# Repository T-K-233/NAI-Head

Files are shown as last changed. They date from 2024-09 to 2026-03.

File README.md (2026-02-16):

# An animatronic head

Note: The original code and report is stored on [ee249 branch](https://github.com/T-K-233/NAI-Head/tree/ee249).

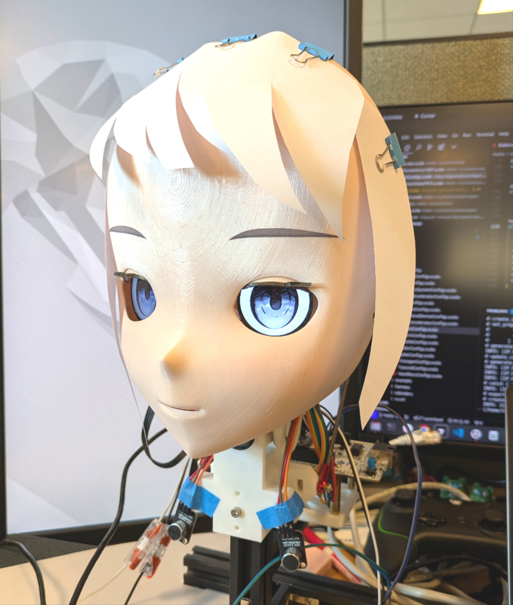
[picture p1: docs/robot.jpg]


This project presents the development of an anime-inspired robotic head designed for cyber-physical systems research, integrating advanced computational techniques, aesthetic considerations, and mechanical engineering. The system features a multi-platform architecture that combines STM32 microcontrollers, FPGA-based gesture recognition, and neural networks deployed on edge AI devices. By coordinating eye and head movements and dynamically responding to user interactions, the robot achieves lifelike and engaging interactions. The implementation of gesture recognition through machine learning, along with finite state machine-based behavior control, enhances the robot's capability for natural human-robot interactions. The mechanical structure, created using OnShape and Blender, supports versatile movement and expressive gestures. 

## Directory Structure

`Baremetal-IDE/` and `Baremetal-NN/` contain the code for setting up a baremetal environment from scratch on RISC-V platforms and runs the neural network inference. It also includes a Python script for C code generation from a PyTorch model.

`firmware/` contains the firmware for the STM32 microcontroller. We use STM32F446 for functional prototyping of each module, and integrate the final project on STM32F429. The `convert.py` script is used to generate the binary RGB565 image from the original PNG file for the LCD display.

`host/` contains bridge code for interacting with the VTubeStudio software.

`MaDa/` contains the code for generating the FPGA bitstream to perform edge inference on RISC-V design on FPGA.

`mechanical/` contains the intermediate files for building the mechanical structure of the robot. The rest of the files are available in the [Onshape project](https://cad.onshape.com/documents/7b6f8264bfc266305901c995/w/1ddfe8bb1118d3d58069c09d/e/082a5b68c1e32d8598ae1104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).

`neural/` contains the gesture recognition model and the code for training and inference on host PC.

## Hardware Setup

### Wiring

| Index | Board Pin | STM32 Pin (L) | STM32 Pin (R) | Description |
| ----- | --- | --- | --- | --- |
| 1 | GND | GND | GND | Ground |
| 2 | VIN | 3V3 | 3V3 | Power, 3.3V ~ 5V |
| 3 | SCL | PA5 (SCLK) | PB13 (SCLK) | SPI clock input |
| 4 | SDA | PA7 (MOSI) | PB15 (MOSI) | SPI data input |
| 5 | RES | PA9 | PB2 | Reset, active low |
| 6 | DC | PA8 | PB1 | Data / Command select, low: command; high: data  |
| 7 | CS | PB6 | PA11 | SPI chip select, active low |
| 8 | BLK | PC7 | PB12 | Backlight enable, default pull-up to 3V3 |

### Peripheral Allocation

#### SPI

- Frame Format: Motorola
- Data Size: 8 bits
- First Bit: MSB First
- Baud Rate: 20 Mbps
- Clock Polarity: Low
- Clock Phase: 1st Edge
- NSS Signal: Software Controlled

#### Timer

- Prescaler: 79
- Counter Mode: Up
- Counter Period: 19999
- PWM Generation
  - PWM Mode: Mode 1
  - Pulse: 1500
  - Output Compare Preload: Enable
  - Fast Mode: Disable
  - CH Polarity: High
 
### Clock Tree Settings

SPI1 and TIM1, TIM8 are under the high speed APB2 bus; SPI2 and TIM2-7 are under APB1 bus. This information can be verified in Table 1 of [RM0090
Reference manual](https://www.st.com/resource/en/reference_manual/dm00031020-stm32f405-415-stm32f407-417-stm32f427-437-and-stm32f429-439-advanced-arm-based-32-bit-mcus-stmicroelectron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).

APB1 bus is configured to have 40 MHz clock (PCLK1 = 40 MHz, 45 MHz max); APB2 bus is configured to have 80 MHz clock (PCLK2 = 80MHz, 90 MHz max).

We need to configure the prescaler of each peripheral accordingly.

### Communication Frame

#### UDP Frame

| Idx | Name | Byte Range | Type |
| --- | --- | --- | --- |
| 0 | Head X | 0:4 | float32 |
| 1 | Head Y | 4:8 | float32 |
| 2 | Head Z | 8:12 | float32 |
| 3 | Eye Left X | 12:16 | float32 |
| 4 | Eye Left Y | 16:20 | float32 |
| 5 | Eye Right X | 20:24 | float32 |
| 6 | Eye Right Y | 24:28 | float32 |
| 7 | Eye Left Openness | 28:32 | float32 |
| 8 | Eye Right Openness  | 32:36 | float32 |

## Solving Protobuf issue in Windows

```powershell
$env:PROTOCOL_BUFFERS_PYTHON_IMPLEMENTATION = "python"
```

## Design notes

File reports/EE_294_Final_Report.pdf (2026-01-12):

# An Anime Figure Robot Head for Cyber-Physical Systems Research

Yufeng Chi∗
chiyufeng@berkeley.edu

Jingyi Xu∗
jingyixu@berkeley.edu

Abstract—This project presents the development of an anime-inspired robotic head designed for cyber-physical systems research, integrating advanced computational techniques, aesthetic considerations, and mechanical engineering. The system features a multi-platform architecture that combines STM32 microcontrollers, FPGA-based gesture recognition, and neural networks deployed on edge AI devices. By coordinating eye and head movements and dynamically responding to user interactions, the robot achieves lifelike and engaging interactions. The implementation of gesture recognition through machine learning, along with finite state machine-based behavior control, enhances the robot’s capability for natural human-robot interactions. The mechanical structure, created using OnShape and Blender, supports versatile movement and expressive gestures. This work not only addresses challenges like the uncanny valley effect but also establishes a foundation for future advancements in humanoid robotic systems, with potential applications in entertainment, education, and human-computer interaction.

I. INTRODUCTION
The design and functionality of humanoid robots have advanced significantly in recent years, yet achieving natural and engaging human-robot interactions remains a considerable challenge. A key obstacle is the ”uncanny valley” effect [6, 7], where robots that closely resemble humans but display subtle imperfections in appearance or behavior evoke discomfort or unease in observers. Addressing this phenomenon requires a combination of stylized aesthetic design [5] and smooth, responsive motion control to enhance user perception and interaction quality.
Al-Sada et al. approaches this challenge by implementing a humanoid robot that incorporates anime-inspired behaviors and interactions, utilizing teleoperation and imitation-learned control policies. However, their work does not fully explore the computational requirements or input modalities needed for a seamless user experience.
Building on these concepts, this work introduces an anime-styled robotic head equipped with multiple computing components, shown in Figure 1, designed to express emotions through coordinated eye and head movements while dynamically responding to user interactions. This platform serves as a foundation for exploring advanced motion control strategies and optimizing workload scheduling for multitenant systems, ultimately contributing to more fluid and lifelike human-robot interactions. The codebase can be accessed from https: //github.com/T-K-233/NAI-Head.

*These authors contributed equally to this work


Fig. 1: The anime-styled robotic head with ability to express motions via eye and head movements.

II. THE ROBOT PLATFORM

The system is composed of three compute platforms. The host computer reads in camera frames from the camera and performs the front-end detection of the user gesture. The detected hand keypoints will then be sent to the RISC-V processor running on Arty FPGA for classification and detects a motion label from the landscape. Lastly, the user gesture is transmitted to the STM32 microcontroller, which controls both the microphones, the TFT LCD screens, and the various servo actuators. The system are connected together with Ethernet interface under a same local subnet, and the data packets are transmitted with UDP frames. In Section III we introduce the workload and static scheduling on the STM32 microcontroller; in Section IV we introduce the neural network running on baremetal environment; and in Section VII we introduce the software running on the host PC.
The mechanical structure of the robot is designed with OnShape and Blender, and manufactured with 3D printing fabrication method. More detail on this is covered in Section VIII

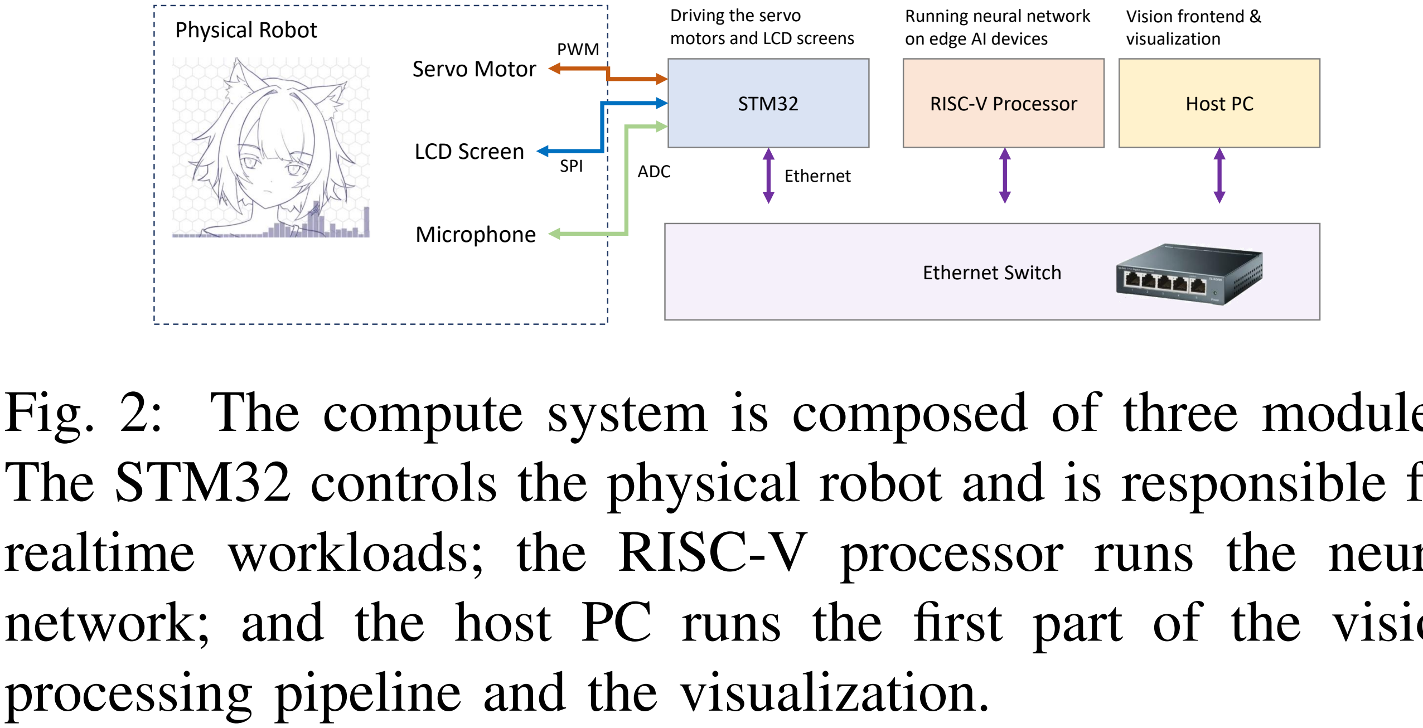
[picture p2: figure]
Ethernet Switch; STM32; Physical Robot; RISC-V Processor; Host PC; Servo Motor; LCD Screen; PWM; ADC; Ethernet; Running neural network on edge AI devices; Driving the servo motors and LCD screens; Vision frontend & visualization; Microphone; SPI; processing pipeline and the visualization.

Fig. | 2: The compute system is composed of three modules.
The | STM32 controls the physical robot and is responsible | for
realtime workloads; the RISC-V processor runs the neural network; and the host PC runs the first part of the vision

III. THE STM32 MICROCONTROLLER

The STM32 microcontroller is responsible for real-time sensing and control of the robot’s input/output (I/O) operations.
Given the platform’s resource constraints and the strict deadlines associated with multiple real-time tasks, a feasible static schedule is crucial to ensure timely and successful program execution.
A. Processor Selection

The STM32 product family offers a wide range of options for embedded processing. The STM32F429ZI microcontroller unit (MCU) was selected based on the following criteria:
- Availability of the Nucleo development board for the selected MCU.
- Availability of required I/O ports, particularly the Ethernet port.
- Availability of resources, such as tutorials and example projects.
- Cost-effectiveness of the development board.
- Compact size and lightweight design.
B. Workload Description

The STM32 controller executes several tasks, prioritized based on their real-time requirements.
1) Audio Sampling
The audio sampling task continuously reads microphone input using the analog-to-digital converter (ADC) at a 25 kHz sampling rate for short durations. While the ADC acquires new samples, previously captured data is transferred to SRAM via direct memory access (DMA) engines.
The microphones are mounted on the same plane, roughly 100 mm apart. Two example signals from the microphone array are shown in Figure 3. A cross-correlation algorithm is then applied to the sampled data from the left and right microphones to determine the time delay corresponding to the peak correlation value. This time delay indicates the angle of the sound source.
2) LCD Control
The LCD driver is another time-sensitive workload. Two TFT LCDs, each driven by the GC9A01A IC, are connected to the STM32 via SPI buses. During each frame update, the driver transmits the coordinates of the first pixel along with

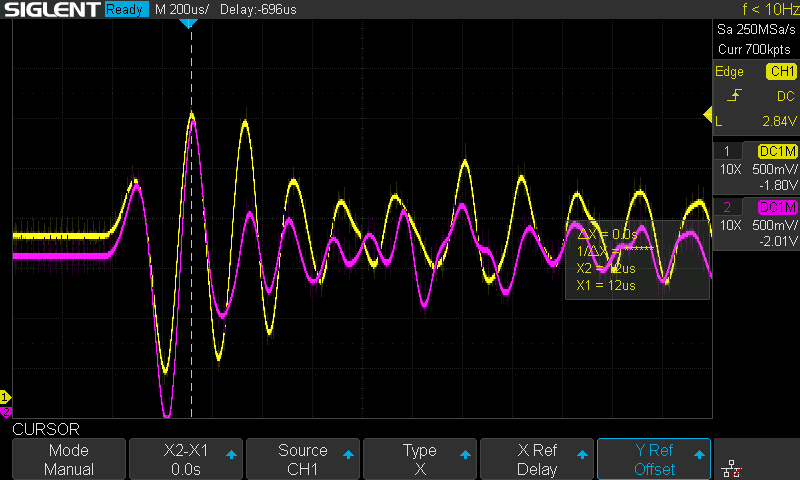
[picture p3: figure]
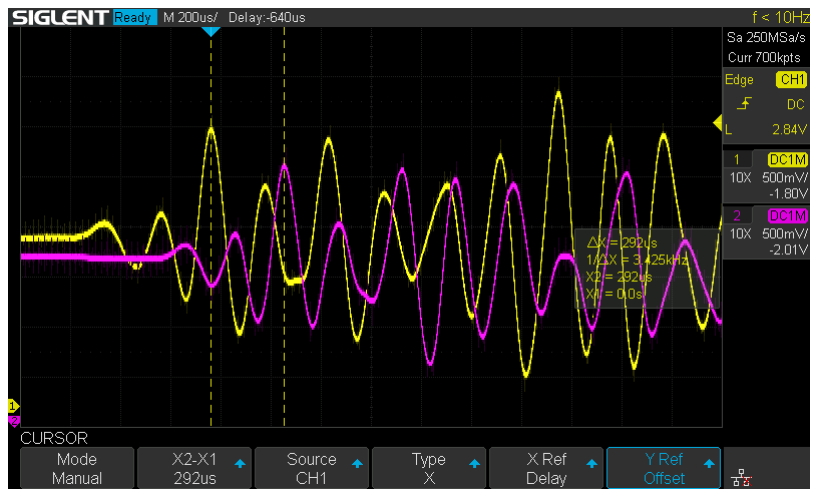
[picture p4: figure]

(a) Sound coming from middle | (b) Sound coming from left
Fig. 3: The analog signals from the microphone. The signals are centered around 1.65V, and the amplitude corresponds to the amplitude of the sound. The phase shift between the two signals roughly translates to the angle of the sound source from the plane of the two microphones.

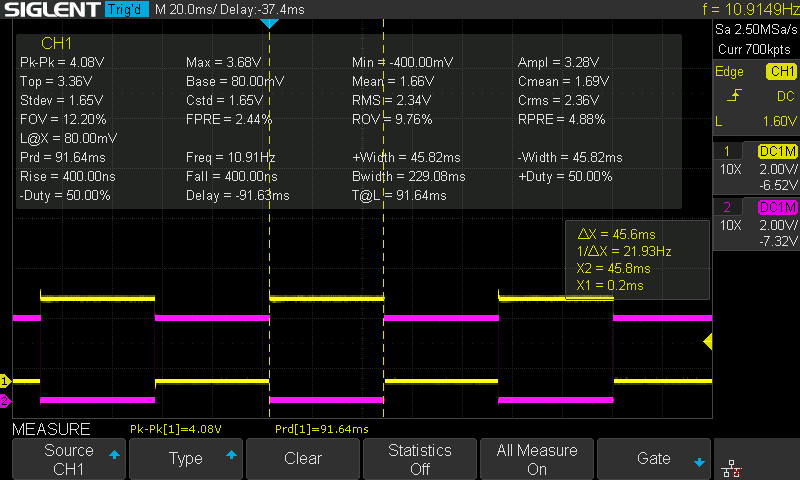
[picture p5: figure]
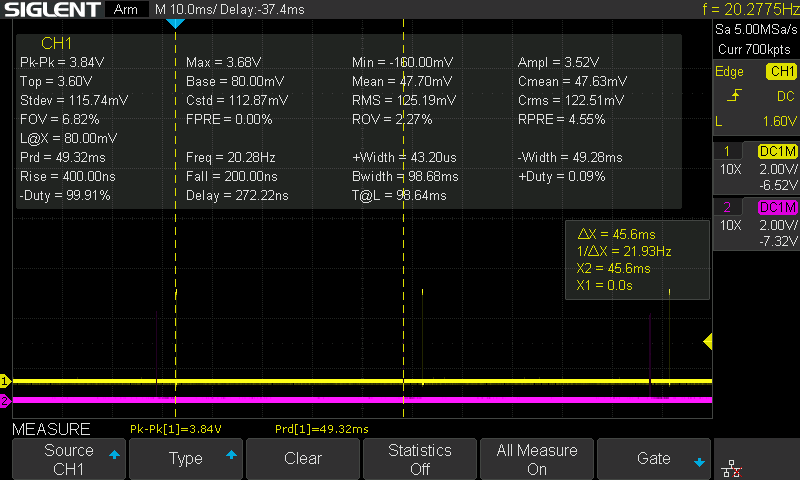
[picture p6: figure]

(a) SPI transmit in polling mode (b) SPI transmit in DMA mode
Fig. 4: The CPU utilization when transmitting SPI data in polling mode and in DMA mode. (a) The yellow line shows the CPU’s state when transmitting on SPI4, where a high level indicates that the CPU actively transmitting, and a low level indicates the CPU is available for other tasks, and the magenta line indiates the CPU state on SPI5. It can be observed that the two SPI transaction takes up entire CPU cycles, which prevents other tasks from being executed. (b) The yellow line shows the begin of a SPI transaction with DMA, and the magenta line shows the corresponding interrupt that configures the CS pin, indicating the end of a transaction.

the image dimensions to the GC9A01A control registers. It then streams pixel data to the display buffer.
Each pixel is encoded in a 565 format, combining 5-bit red, 6-bit green, and 5-bit blue values into two bytes. Given the 240x240 resolution of the LCD, each frame requires transferring 115,200 bytes of data. To reduce CPU load, DMA is employed to handle data transfer, allowing the CPU to perform other tasks concurrently. Figure 4 shows a comparision between using blocking polling transfer and DMA transfer.
3) Servo Control
To control the robot’s five servos, five PWM signals are generated with a 50 Hz period and pulse durations ranging from 500 µs to 2500 µs. The hardware timers on the STM32 are used to generate these PWM signals, minimizing CPU involvement. The CPU only updates the Capture/Compare Register (CCR) values to adjust pulse durations.
4) UDP Communication
The final task involves handling UDP communication between the STM32 and other components of the robot system. The implementation leverages the STM32CubeIDE libraries, which support multiple layers of the OSI model. Specifically:

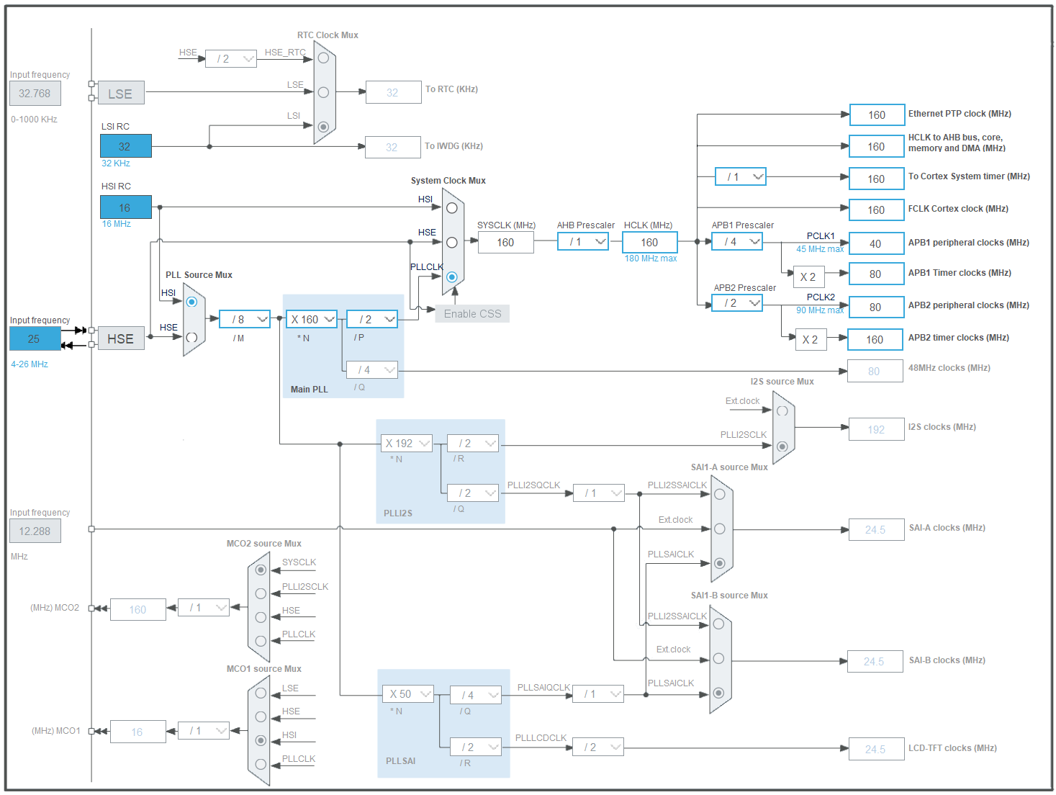
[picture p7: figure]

Fig. 5: The clock tree of the STM32F429ZI. System clock is set to 160 MHz, generated from the main PLL. APB1 and APB2 peripherals are set to their maximum possible clock frequencies, which is 40 MHz and 80 MHz respectively.

- Physical and Data Link Layers: Managed using the
onboard Ethernet (ETH) peripheral.
- Network Layer: Handled by the Lightweight IP (LWIP) stack.
- Transport Layer: Implemented using the example code from Controllerstech.
This modular approach ensures efficient and reliable UDP communication while meeting the real-time constraints of the system.
C. MCU Resource Allocation

Since none of the tasks requires high precision clocks, the clock source of the MCU is configured to be the hightspeed internal RC oscillator (HSI). The system clock is then generated from the on-chip PLL. We select 160 Mhz to be the system clock as it is sufficiently fast, easily dividable into other slower clock domains, and provides enough headroom to the absolute maximum 180 MHz. The resulting clock tree is shown in Figure 5.
Timer 6 and Timer 7 are used to generate interrupt events for SPI and PWM updates. Timer 6 is configured to trigger an interrupt at 10 Hz interval, while Timer 7 is configured to trigger at 50 Hz.
Timer 1 and Timer 4 are used to generate the PWM signal for the five servo motors. They are configured at the start of the application program, and the values are updated in the interrupt handler of Timer 7.

Timer 2 is used as the trigger source for ADC sampling. When update event happens, it generates a signal on the trigger output (TRGO) pin, which will send to the ADC and starts the sampling and conversion. The ADC will then communicate with the DMA engine to perform a predefined number of conversions, and writes the data to a target SRAM location via DMA.
SPI4 and SPI5 are used to drive the TFT LCD screens. For the control commands, they are operating in the blocking polling and in 8-bit mode. After transmitting the command, it is updated to operate in non-blocking DMA mode and in 16-bit transfer mode. Since the chip select (CS) pins are controlled by software, an interrupt handler is set up to write the CS pins high after the data transfer.
Ethernet and the corresponding software library for UDP logic is running entirely in the main thread.
The IOs are planned with the wire harnessing in mind. The resulting pinmap is shown in Figure 6.

IV. THE VISION PIPELINE

The gesture recognition pipelines goes through three stages. First, when users pose, the camera video input is captured and pre-processed. Next, we use mediapipe library to extract the hand keypoints from the image. Lastly, the hand keypoint features are fed into a MLP network to classify the input hand gesture into one of hi, ok, no, point, heart. The output is sent over to STM32 to drive robot behaviors.

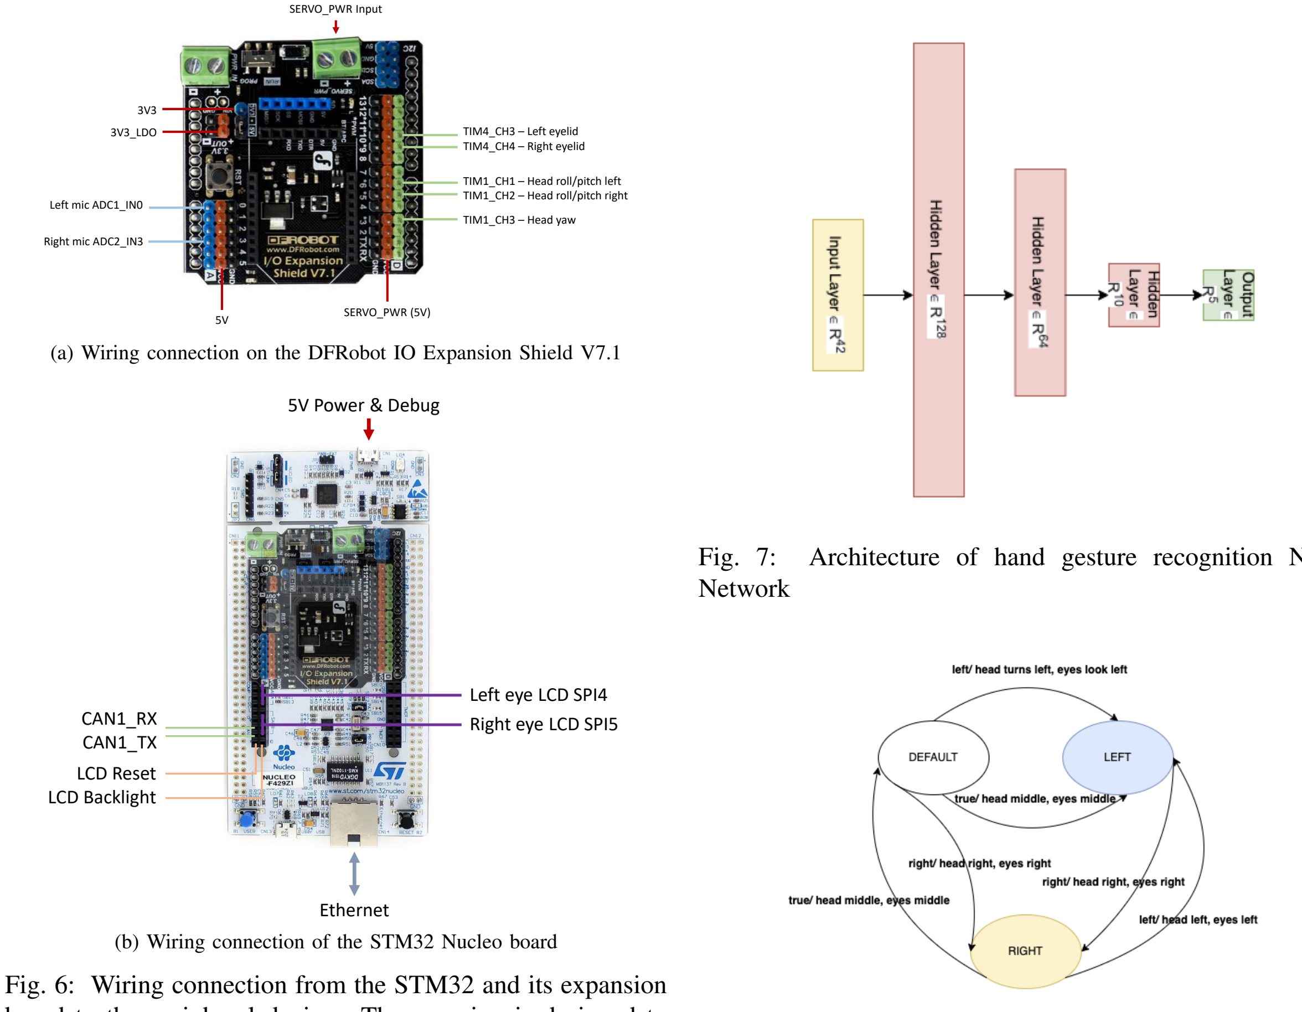
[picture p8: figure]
TIM4_CH3 – Left eyelid TIM4_CH4 – Right eyelid; TIM1_CH1 – Head roll/pitch left TIM1_CH2 – Head roll/pitch right; TIM1_CH3 – Head yaw; SERVO_PWR (5V) 5V; 3V3_LDO; Left mic ADC1_IN0; SERVO_PWR Input; Right mic ADC2_IN3; CAN1_RX CAN1_TX; Ethernet; LCD Reset LCD Backlight; Left eye LCD SPI4 Right eye LCD SPI5; 5V Power & Debug; Network

(a) Wiring connection on the DFRobot IO Expansion Shield V7.1
(b) Wiring connection of the STM32 Nucleo board
Fig. 6: Wiring connection from the STM32 and its expansion board to the peripheral devices. The mapping is designed to group pins with similar functions together.

The model’s architecture is shown in Figure 7. It takes the 21 hand landmarks as input and runs through 3 hidden layers and outputs probabilities for each of the 5 labels, the highest of which selected as prediction label. This model is designed to be lightweight to be deployed on edge computing platforms including K230 and soft RISC-V core on FPGA. To train this model, we collected our custom dataset of 5000 samples. We trained the model from scratch and it achieves 97.2% accuracy.

To port the neural network to embedded runtime, we first implemented the C runtime and syscall handlers (libgloss layer) in Baremetal-IDE. In addition, we built the Baremetal-NN library to convert the pytorch model to embedded RISC-V environment. We successfully ported our custom pytorch model to K230 chip. We also generated a corresponding RISC-V RV32IMAFC TinyRocket SoC design on FPGA, leveraging the Ethernet controller IPs provided by Xilinx to perform UDP communication.

Fig. 7: Architecture of hand gesture recognition Neural

Fig. 8: FSM capturing the robot’s reaction with respect to sound input(from left or right).

V. ROBOT FINITE STATE MACHINE

We define the Robot’s behavior using two finite state machines. The first reacts to input sounds. Figure 8 shows that the robot turns its head and eyes to the direction of sound input.
The robot’s reaction to user’s hand gesture is represented as a one-state Mealy Machines, where the output solely depends on the input. The input/output relation is summarized in the lookup table in Table I.
gesture | eyes | head
Hi | enlarged | tilt
Ok | open | nod
No | closed | shake
Point | wink | tilt
Heart | heart eyes | stay still

TABLE I: The robot’s behavior w.r.t hand gesture inputs.

VI. EMBEDDED RUNTIME

Since we are in a baremetal RISC-V environment, we need to construct the C runtime from the ground up. We build the glossy library, our own implementation of the libgloss layer, to provide the basic startup and C runtime assembly program, as well as the basic implementation of system call routines. On bootup, the program counter (PC) of the Rocket core is pointed at BootROM, located at 0x00010000. Then, the BootROM code will guide the PC to perform basic initializations, and jumps to the base of the on-chip SRAM region located at 0x80000000. There, it enters our start up script ”crt0.S”, which initializes the system state by setting general-purpose registers, floating-point unit (if available), global pointer, thread-local storage, stack pointer, and memory segments (data, BSS). It then invokes global constructors, calls the main function for the primary core, and loops indefinitely after program termination, while secondary cores follow a similar initialization path to run main.
A custom linker script is also created to instruct linker to put sections to corresponding locations. The mapping is shown in Figure 9.

__text_start

.text

.rodata

.data

.tdata

.sdata

.bss

.tbss

.heap

.stack

0x8000_0000

__text_end

__data_start | __data_load_start

__text_load_start

__global_pointer$

__tdata_start

__data_end, __tdata_end __tbss_start

__tbss_end __bss_start

__bss_end

__end, __head_start

__head_end

__stack_start

__sp, __stack_end

Fig. 9: Memory map specified by the linker script. The map starts at SRAM base address at 0x80000000, and follows the convention of text, data, heap, and stack layout. The left side shows the symbols pointing to logical address, and the right side shows the symbols with physical address. The gray bar shows the different alignment of sections.

VII. HOST PC SOFTWARE

The host PC runs the vision frontend software, serving as an additional interface to interact with the system. Live video inputs are processed and displayed on the screen, with hand keypoints highlighted. This provides users with visual feedback on the captured scene and the recognized gestures. Additionally, a visualization software is integrated to the system to sync actions from the STM32. VTubeStudio [4] is used as the software platform, which provides high range of motions and can build one-to-one motion mapping with the robot movements. A Python library is implemented to serve as the streaming bridge between the UDP communication used

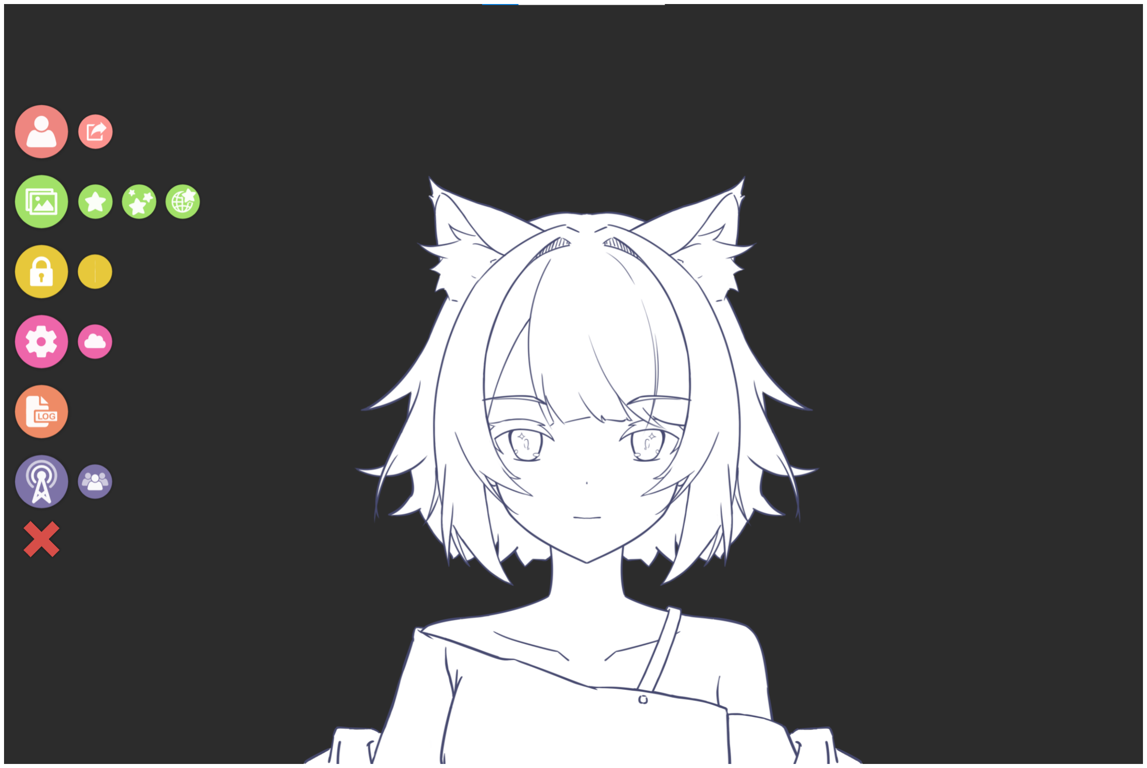
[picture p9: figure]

Fig. 10: On the host PC, VTubeStudio is used to provide a visualization of the robot state. The state is received from the STM32 via UDP, is passed through the custom UDP to Websocket bridge in Python, and sent to the software through its API.

in the robot system and the WebSocket used to communicate with VTubeStudio APIs.

VIII. MECHANICAL DESIGN

We design the mechanical structure of the robot to support roll, pitch, and yaw movement on the neck, and blinking on the eyelid. The internal structure is designed with trial and error. Several design tricks are employed to improve the efficiency of the design flow and the reliability of the resulting structure.

A. Organic Shape Modeling

We generate the 3D model of the anime-styled face from VRoid Studio, which supports exporting to Blender via the vrm format.

B. Harnessing

Due to the limited spacing in the eye socket, it is hard to connect normal signal cables to the TFT LCD screen. Instead, we sourced the LCD screen modules that support connection via ribbon cables. We then adapt the ribbon cables back to the 2.54 mm jumper cables with a breakout board. This improvement greatly increases the reliability of the SPI signal connection, allowing us to run SPI up to 20 MHz

C. IGES File Format

We used Onshape and Blender together to design the organic shape of the robot face and the engineering structure that supports the components. After experimenting with the several 3D file format supported by these softwares, the Initial Graphics Exchange Specification (IGES) format [8] is selected due to its capability of expressing complex planes in Onshape in an editable fashion.

IX. CONCLUSION

In conclusion, this project demonstrates a comprehensive approach to designing an anime-inspired robotic head for cyber-physical systems research, integrating aesthetics, mechanics, and advanced computational techniques. By leveraging a multi-platform system architecture and employing innovative workload management strategies, the robot achieves lifelike interactions and real-time responsiveness. The integration of gesture recognition and finite state machine-based behavior control highlights the potential for expanding human-robot interaction capabilities. Future work could explore the scalability of the system, the incorporation of additional sensory modalities, and further optimization of the neural network pipeline to enhance performance and adaptability. This endeavor not only bridges the gap between technology and creativity but also sets a foundation for advancing userfriendly humanoid robotic systems.

ACKNOWLEDGMENT
We would like to acknowledge BlueArrow for providing the servo motors used in the robot platform. We would also like to acknowledge ”SiHaiMoYu” on Bilibili for kindly providing the Live2D model.

REFERENCES
[1] Mohammed Al-Sada, Pin-Chu Yang, Chang Chieh Chiu, Tito Pradhono Tomo, Mhd Yamen Saraiji, Tetsuya Ogata, and Tatsuo Nakajima. From anime to reality: Embodying an anime character as a humanoid robot. In Extended Abstracts of the 2021 CHI Conference on Human Factors in Computing Systems, pages 1–5, 2021.
[2] Alon Amid, David Biancolin, Abraham Gonzalez, Daniel Grubb, Sagar Karandikar, Harrison Liew, Albert Magyar, Howard Mao, Albert Ou, Nathan Pemberton, et al. Chipyard: Integrated design, simulation, and implementation framework for custom socs. IEEE Micro, 40(4):10–21, 2020.
[3] Controllerstech. Stm32 ethernet - udp server, 2024. URL https://controllerstech.com/stm32-ethenret-2-udp-server/. Accessed: 2024-06-16.
[4] Denchisoft. Denchisoft official website. https://denchisoft.com/. Accessed: 2024-12-18.
[5] Tom Geller. | Overcoming the uncanny valley. | IEEE
computer graphics and applications, 28(4):11–17, 2008.
[6] Roger K Moore. A bayesian explanation of the ‘uncanny valley’effect and related psychological phenomena. Scientific reports, 2(1):864, 2012.
[7] Jun’ichiro Seyama and Ruth S Nagayama. The uncanny valley: Effect of realism on the impression of artificial human faces. Presence, 16(4):337–351, 2007.
[8] Brad Smith and Joan Wellington. Initial graphics exchange. Specification (IGES), Version, 3, 1986.

APPENDIX A
FPGA COMPUTE
To generate a RISC-V SoC design on FPGA, we leveraged Chipyard [2], an agile RISC-V SoC design framework. We used the TinyRocketConfig and modified the on-chip scratchpad SRAM size to 2048 kB. We also attached an external AXI bus to integrate with the external verilog IPs from Xilinx and other open-source projects.
One barrier we have encountered is that due to the cake config pattern design used by Chipyard, it is hard to customize the IO connection and pin map of the SoC design on the target FPGA. To address this, we implemented a wrapper framework in Chisel with the Mill build system. The framework wraps around the DigitalTop module generated by Chipyard, and connects the signals between DigitalTop, other IP blocks, and the FPGA IOs manually.
We use Vivado 2024.2 to synthesize the hardware design on Digilent Arty 35T, which uses 15274 LUTs and 11 blocks of BRAM.
We then use JTAG to upload the baremetal program that interfaces with the Ethernet controller and performs the neural network forward inference.

APPENDIX B
STM32 PROGRAMMING
A detailed writeup of the procedure of configuring various STM32 peripheral components can be accessed at https://notes.tk233.xyz/stm32/getting-started-stm32-edition

APPENDIX C
RISC-V BAREMETAL RUNTIME
A more detailed, step-by-step explanation of how we set up the components of the RISC-V baremetal runtime can be accessed at https://notes.tk233.xyz/risc-v-soc/risc-v-baremetal-from-the-ground-up-chipyard-edition

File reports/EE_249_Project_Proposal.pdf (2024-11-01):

## EE 249 Project Proposal

## 1 Team

Yufeng Chi
chiyufeng@berkeley.edu

Jingyi Xu
jingyixu@berkeley.edu

## 2 Overview

This project aims to build a very cute anime figure robot head, capable of expressing emotions through eye and head movements and responses to user hand gestures. When the user makes a pointing gesture, the figure will track and stares at the user’s fingertip. A digital twin will also be created to provide a visualization on the real robot’s state.

### 2.1 Key Ideas

- Interfacing with servo motors and LCD screens
- Running neural networks on RISC-V embedded platforms
- The Ethernet communication stack
- Making Custom PCBs (?)

## 3 Approach

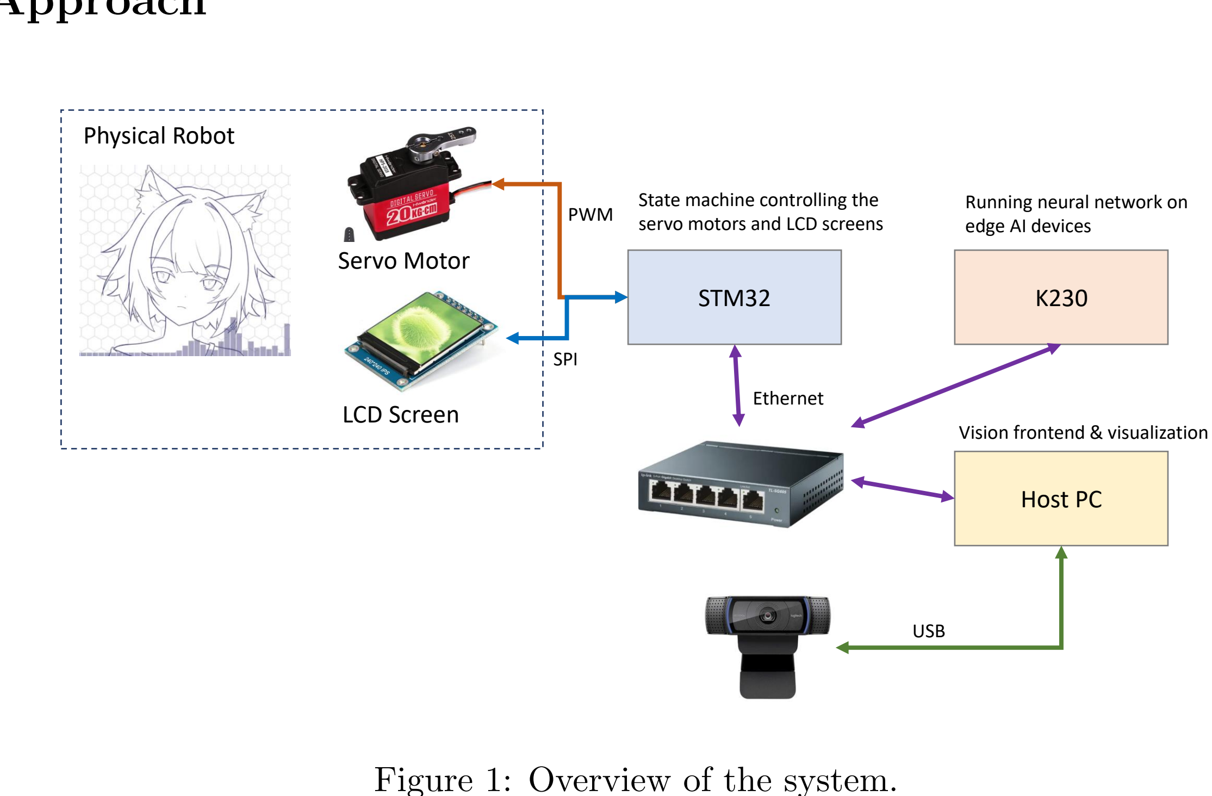
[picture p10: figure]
STM32; Physical Robot; Host PC; Servo Motor; LCD Screen; PWM; SPI; Ethernet; USB; Running neural network on edge AI devices; State machine controlling the servo motors and LCD screens

Vision frontend & visualization Figure 1: Overview of the system.

The system will be composed of three compute platforms. An overview of the system is provided in Figure 1. The servo and LCD screens will be driven by the STM32 processor. The host computer will perform the front-end detection of the user gesture, which takes RGB image frames from the USB camera and detects the hand keypoint landmarks. The visualization software will also run on the host computer. The K230 RISC-V SoC will then takes the landmark and passes through a CNN-based network to detect user gesture. The system will be connected together with Ethernet interface, and the data packets will be transmitted with UDP frames. If time allows, we will port more neural network workloads onto the K230 SoC to enhance the capability of the robot.
The mechanical structure of the robot will be designed with OnShape CAD software, and be manufactured with 3D printing. Since this is not the primary focus of the project, we will leverage some prior works.

1

## 4 Resources

Hardware Components

- STM32 NUCLEO-F429ZI development board
- Kendryte K230 RISC-V development board with RVV 1.0 instruction set support
- Desktop PC with Ethernet port
- Bambu Lab 3D printer and filaments

Software

- Cursor the AI code editor
- STM32CubeIDE
- OnShape
- Altium Designer
- VTube Studio
- Github Repository: git@github.com:T-K-233/NAI-Head.git

## 5 Schedule

2024-10-30 Finish project proposal (this document).
2024-11-05 Finish most of the mechanical integration; Finish STM32 code; Have a training environment of the hand-detection neural network.
2024-11-11 Finish network training; Port the network onto K230 device; Finish UDP communication between system components.
2024-11-18 No work. Review for Midterm.
2024-11-25 System integration and testing.
2024-12-02 Draft of demo videos and presentation slides.
2024-12-09 Buffer week. Bug fixes.
2024-12-16 Final version of demo, video, and posters.
2024-12-23 Project summary video uploaded to YouTube and Bilibili.

## 6 Risk Mitigation

There are many unknowns. The system integration might take longer than expected. The neural network might be difficult to train. We decide to follow the lean design methodology and focus on getting a minimum-viable product ready at each stage to have a better control over the timeline.

2

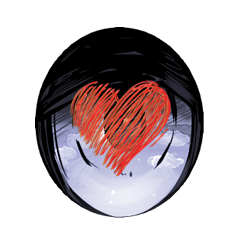
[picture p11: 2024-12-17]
firmware/iris_heart.png

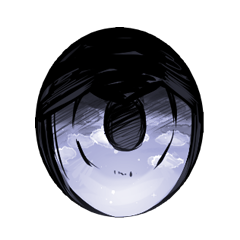
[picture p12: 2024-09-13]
firmware/iris.png

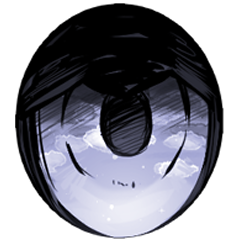
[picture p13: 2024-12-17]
firmware/iris_large.png

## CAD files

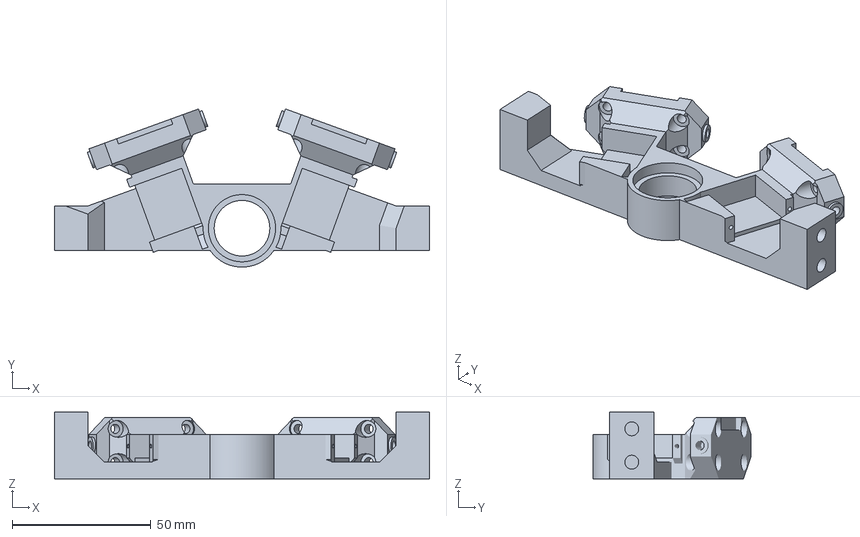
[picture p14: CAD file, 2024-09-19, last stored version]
mechanical/Eye LCD Mount.3mf
135.0 x 56.9 x 24.0 mm

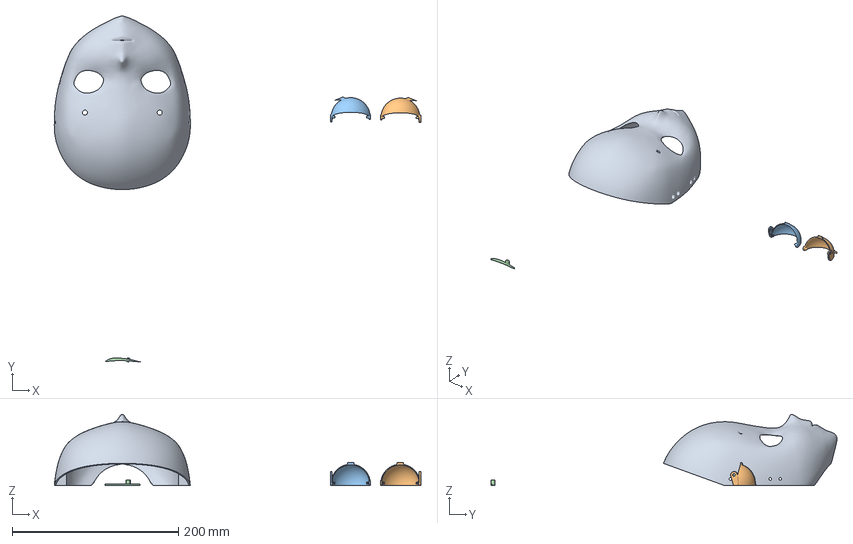
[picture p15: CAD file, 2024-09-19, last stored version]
mechanical/Skin Parts.3mf
441.5 x 416.8 x 85.8 mm
Face - Face.stl
Eye Lid - Eyelash R.stl x 2
Eyebrow - Eyebrow.stl

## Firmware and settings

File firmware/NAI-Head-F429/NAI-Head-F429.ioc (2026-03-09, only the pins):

Mcu.UserName=STM32F429ZITx
PA1.Signal=ETH_REF_CLK
PA13.Signal=SYS_JTMS-SWDIO
PA14.Signal=SYS_JTCK-SWCLK
PA2.Signal=ETH_MDIO
PA3.Signal=ADCx_IN3
PA7.Signal=ETH_CRS_DV
PB11.Signal=GPIO_Output
PB13.Signal=ETH_TXD1
PC0.Signal=ADCx_IN10
PC1.Signal=ETH_MDC
PC4.Signal=ETH_RXD0
PC5.Signal=ETH_RXD1
PD0.Signal=CAN1_RX
PD1.Signal=CAN1_TX
PD14.Signal=S_TIM4_CH3
PD15.Signal=S_TIM4_CH4
PD8.Signal=USART3_TX
PD9.Signal=USART3_RX
PE0.Signal=GPIO_Output
PE11.Signal=S_TIM1_CH2
PE13.Signal=S_TIM1_CH3
PE2.Signal=SPI4_SCK
PE3.GPIO_Label=GPIO_SPI5_CS
PE3.Signal=GPIO_Output
PE4.GPIO_Label=GPIO_SPI4_CS
PE4.Signal=GPIO_Output
PE5.GPIO_Label=GPIO_SPI4_DC
PE5.Signal=GPIO_Output
PE6.Signal=SPI4_MOSI
PE9.Signal=S_TIM1_CH1
PF7.Signal=SPI5_SCK
PF8.GPIO_Label=GPIO_SPI5_DC
PF8.Signal=GPIO_Output
PF9.Signal=SPI5_MOSI
PG0.GPIO_Label=GPIO_LCD_RESET
PG0.Signal=GPIO_Output
PG1.GPIO_Label=GPIO_LCD_BLK
PG1.Signal=GPIO_Output
PG11.Signal=ETH_TX_EN
PG13.Signal=ETH_TXD0
PH0/OSC_IN.Signal=RCC_OSC_IN
PH1/OSC_OUT.Signal=RCC_OSC_OUT

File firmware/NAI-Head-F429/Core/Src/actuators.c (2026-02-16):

/*
 * neck_control.c
 *
 *  Created on: Dec 14, 2024
 *      Author: TK
 */

 #include "actuators.h"


 void robot_actuator_init(
     ActuatorControl *robot,
     TIM_HandleTypeDef *eyebrow_htim,
     uint32_t eyebrow_left_channel,
     uint32_t eyebrow_right_channel,
     TIM_HandleTypeDef *eyelid_htim,
     uint32_t eyelid_left_channel,
     uint32_t eyelid_right_channel
   ) {
   robot->eyebrow_htim = eyebrow_htim;
   robot->eyebrow_left_channel = eyebrow_left_channel;
   robot->eyebrow_right_channel = eyebrow_right_channel;
 //  robot->neck_yaw_channel = neck_yaw_channel;
   robot->eyelid_htim = eyelid_htim;
   robot->eyelid_left_channel = eyelid_left_channel;
   robot->eyelid_right_channel = eyelid_right_channel;
 
   // enable PWM outputs
   HAL_TIM_PWM_Start(robot->eyebrow_htim, robot->eyebrow_left_channel);
   HAL_TIM_PWM_Start(robot->eyebrow_htim, robot->eyebrow_right_channel);
 
   HAL_TIM_PWM_Start(robot->eyelid_htim, robot->eyelid_left_channel);
   HAL_TIM_PWM_Start(robot->eyelid_htim, robot->eyelid_right_channel);
 }
 
 void robot_set_eyebrow(ActuatorControl *robot, float left, float right) {
   left = clampf(left, -1.f, 1.f);
   right = clampf(right, -1.f, 1.f);
 
 
   uint16_t left_pwm_value = EYEBROW_L_FLAT;
   uint16_t right_pwm_value = EYEBROW_R_FLAT;
 
   if (left > 0) {
     left_pwm_value += left * (EYEBROW_L_FULL_RAISE - EYEBROW_L_FLAT);
   }
   else {
     left_pwm_value -= (-left) * (EYEBROW_L_FLAT - EYEBROW_L_FULL_DOWN);
   }
 
   if (right > 0) {
     right_pwm_value -= right * (EYEBROW_R_FLAT - EYEBROW_R_FULL_RAISE);
   }
   else {
     right_pwm_value += (-right) * (EYEBROW_R_FULL_DOWN - EYEBROW_R_FLAT);
   }
 
   __HAL_TIM_SET_COMPARE(robot->eyebrow_htim, robot->eyebrow_left_channel, left_pwm_value);
   __HAL_TIM_SET_COMPARE(robot->eyebrow_htim, robot->eyebrow_right_channel, right_pwm_value);
 }
 
 
 void robot_set_eyelid(ActuatorControl *robot, float left_eye_openness, float right_eye_openness) {
   left_eye_openness = clampf(left_eye_openness, 0.f, 1.f);
   right_eye_openness = clampf(right_eye_openness, 0.f, 1.f);
 
   uint16_t left_pwm_value = EYELID_L_FULL_CLOSE * (1 - left_eye_openness) + EYELID_L_FULL_OPEN * left_eye_openness;
   uint16_t right_pwm_value = EYELID_R_FULL_CLOSE * (1 - right_eye_openness) + EYELID_R_FULL_OPEN * right_eye_openness;
 
   __HAL_TIM_SET_COMPARE(robot->eyelid_htim, robot->eyelid_left_channel, left_pwm_value);
   __HAL_TIM_SET_COMPARE(robot->eyelid_htim, robot->eyelid_right_channel, right_pwm_value);
 }
 
 

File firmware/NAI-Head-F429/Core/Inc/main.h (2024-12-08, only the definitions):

#define MEM_ALIGNMENT                   4
#define GPIO_SPI5_CS_Pin GPIO_PIN_3
#define GPIO_SPI5_CS_GPIO_Port GPIOE
#define GPIO_SPI4_CS_Pin GPIO_PIN_4
#define GPIO_SPI4_CS_GPIO_Port GPIOE
#define GPIO_SPI4_DC_Pin GPIO_PIN_5
#define GPIO_SPI4_DC_GPIO_Port GPIOE
#define GPIO_SPI5_DC_Pin GPIO_PIN_8
#define GPIO_SPI5_DC_GPIO_Port GPIOF
#define GPIO_LCD_RESET_Pin GPIO_PIN_0
#define GPIO_LCD_RESET_GPIO_Port GPIOG
#define GPIO_LCD_BLK_Pin GPIO_PIN_1
#define GPIO_LCD_BLK_GPIO_Port GPIOG

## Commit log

2024-09-19 ADD: add 3d print files
    [Eye LCD Mount.3mf, Skin Parts.3mf]
2024-10-30 REFACTOR: rename folder
    [Eye LCD Mount.3mf, Skin Parts.3mf]
2024-12-08 ADD: integrate two SPI screens
2024-12-15 ADD: DMA SPI, pushing refresh to 20 Hz
2024-12-17 ADD: socket
2024-12-17 ADD: collected gesture data
    [keypoint.csv, keypoint_classifier_label.csv]
2024-12-17 ADD: servo calibration
2026-02-16 UPDATE: bump STM32 project version
2026-02-16 REMOVE: repo cleanup
    [Eye LCD Mount.3mf, Skin Parts.3mf, keypoint.csv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]
2026-02-16 REFACTOR: switch to use pyvts and uv
2026-03-10 add: neck actuator code

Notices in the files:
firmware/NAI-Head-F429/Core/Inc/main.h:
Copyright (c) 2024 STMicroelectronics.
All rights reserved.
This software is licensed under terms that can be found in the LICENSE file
